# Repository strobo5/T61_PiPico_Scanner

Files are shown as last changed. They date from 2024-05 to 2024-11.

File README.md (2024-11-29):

Keyboard scanner for a Thinkpad T61 keyboard, using the original connector,
salvaged from a retired T61, and a Raspberry Pi Pico H. Components on the BOM:

* 1x Molex 54363-0489 (WM6787CT-ND on Digikey)
* 1x Raspberry Pi Pico (with or without headers)
* 1x capacitor SMD 0603 2.2 uF
* 1x capacitor SMD 0603 100 nF
* 1x p-MOSFET TSM2305CX or similar (optional, for external 5V, e.g. a battery)
* 2x n-MOSFET 2N7002 or similar
* 4x resistor SMD 0603 10 kOhm
* 1x resistor SMD 0603 22 kOhm

Based on work by thedalles77 (schematics) and WarhawkCZ (QMK variant). HDR also
had the same idea of having the keyboard connector and the MCU module on
opposite sides to save space.
- https://github.com/thedalles77/USB_Laptop_Keyboard_Controller/tree/master/Example_Keyboards/Lenovo_ThinkPad_T61/Teensy%20LC
- https://forum.thinkpads.com/viewtopic.php?t=134293
- https://github.com/HDR/USB_Laptop_Keyboard_Controller

Thanks @tpcware for the KiCad symbol, footprint and 3D model for the Raspberry
Pi Pico. I butchered the footprint to get a THT-only variant.
https://github.com/ncarandini/KiCad-RP-Pico

Good advice came from thedalles77 on instructables to lay out the connections
on a piece of paper before assigning the nets in the schematic editor.
https://www.instructables.com/How-to-Make-a-USB-Laptop-Keyboard-Controller/

When using a Pico W it might be possible to extend this with Bluetooth, hence
the solder pads for wires to an external battery charger + 5V converter. This
might not work too well though; the keyboard's bottom is a metal shield that
probably kills the wireless transmission when the Pico W is right underneath.

Ordered on JLCPCB. The via size (0.5 mm hole, 1.1 mm overall diameter) is small
enough and does not cost extra.

The 0.5 mm drills and vias could be done by hand (with wire soldered through
the hole) if making the PCB at home.

## Third-party components

The following components in this repository are not my work:

Symbols:

* AA01B-S040VA1 - probably by Jiri Panacek (WarhawkCZ)
* Molex_54363-0489:543630489 - Copyright held by EMA Design Automation, ® Inc., all rights reserved

Footprints:

* T61_Kb_Scanner:RPi_Pico_H - adapted from the one by @tpcware
* T61_Kb_Scanner:AA01B-S040VA1 - unknown
* T61_Kb_Scanner:WM6787CT-ND - unknown
* Molex_54363-0489:CON_543630489 - Copyright held by EMA Design Automation, ® Inc., all rights reserved

## License

Copyright 2023-2024 Michael Büchler
SPDX-License-Identifier: Apache-2.0 WITH SHL-2.1

The schematics and PCB design in this repository shall use the Solderpad Hardware License v 2.1 (the “License”); you may not use this file except in compliance with the License, or, at your option, the Apache License version 2.0. You may obtain a copy of the License at

https://solderpad.org/licenses/SHL-2.1/

Unless required by applicable law or agreed to in writing, any work distributed under the License is distributed on an “AS IS” BASIS, WITHOUT WARRANTIES OR CONDITIONS OF ANY KIND, either express or implied. See the License for the specific language governing permissions and limitations under the License.

## Images

The keyboard case in the picture is this one:
https://www.printables.com/model/877321-thinkpad-t61-keyboard-base

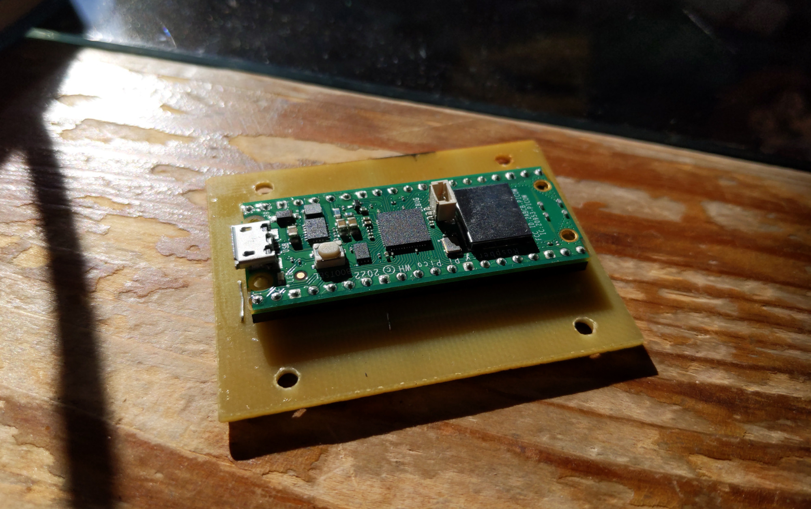
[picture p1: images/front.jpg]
PCB top

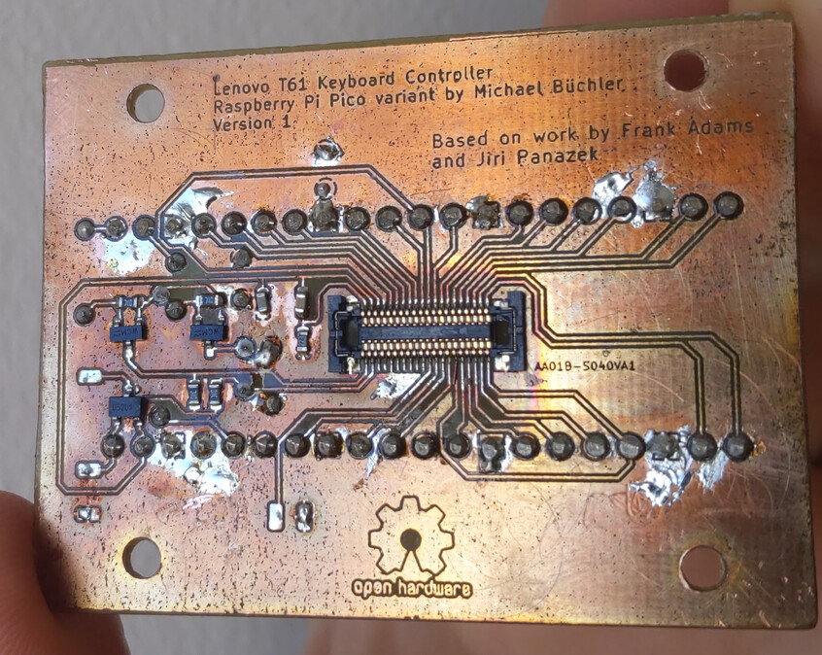
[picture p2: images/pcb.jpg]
PCB bottom

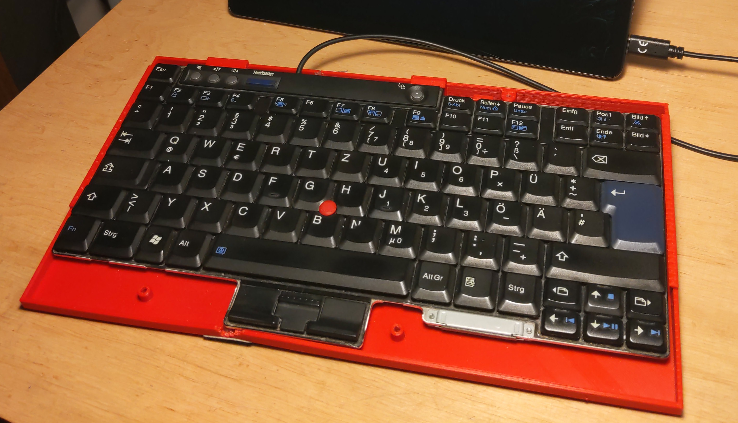
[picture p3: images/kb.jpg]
Assembled keyboard


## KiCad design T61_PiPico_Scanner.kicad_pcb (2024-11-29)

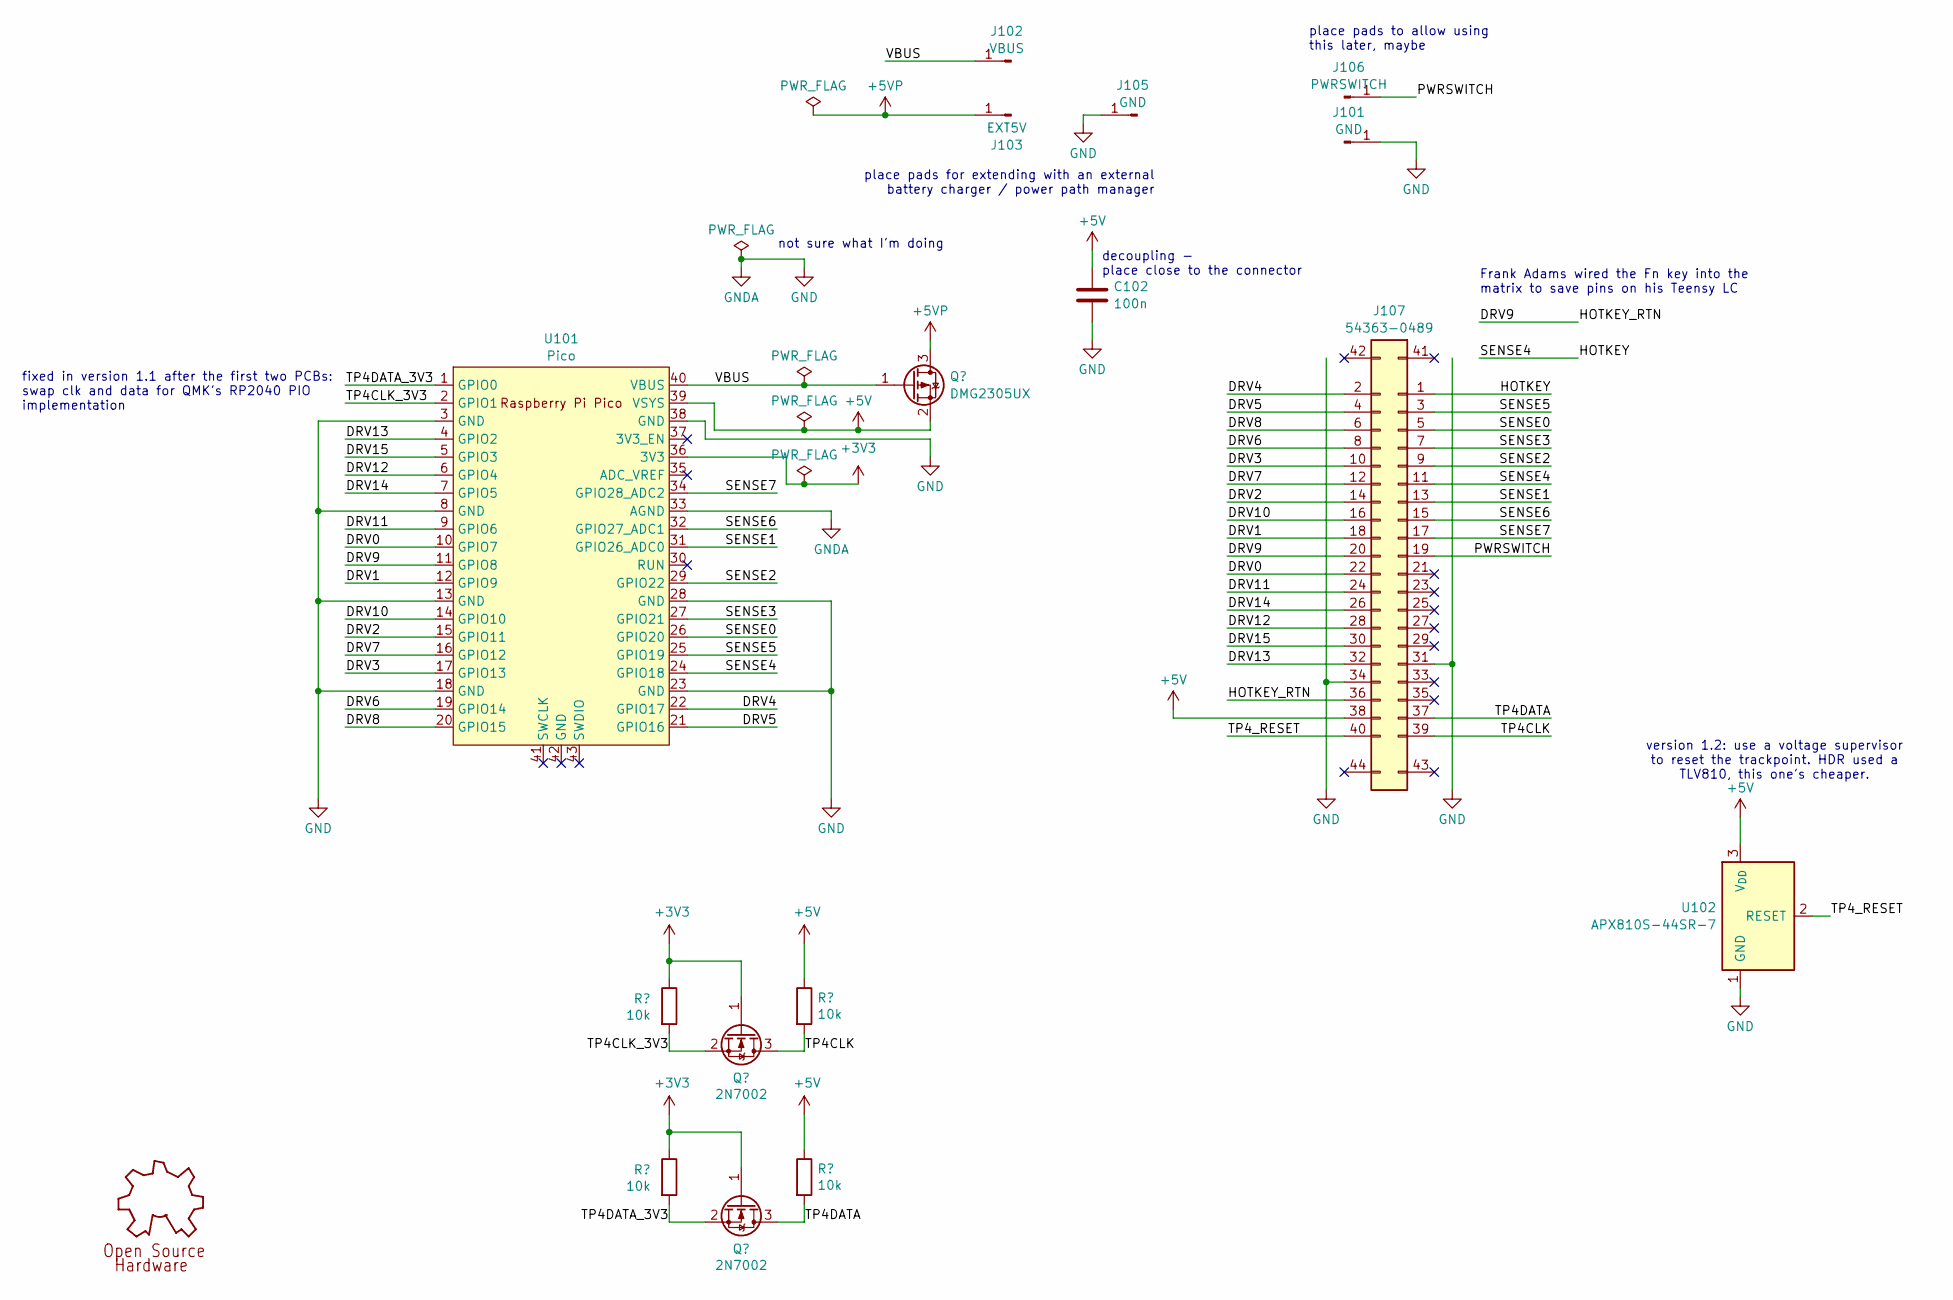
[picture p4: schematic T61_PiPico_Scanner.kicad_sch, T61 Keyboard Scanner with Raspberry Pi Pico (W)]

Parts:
C102: 100n; C_0603_1608Metric
GOLD_ORB_SM101: OSHWLOGOLOGO5MM; OSHW-Logo_5.7x6mm_Copper
J101, J105: GND; SolderWirePad_1x01_SMD_1x2mm
J102: VBUS; SolderWirePad_1x01_SMD_1x2mm
J103: EXT5V; SolderWirePad_1x01_SMD_1x2mm
J106: PWRSWITCH; SolderWirePad_1x01_SMD_1x2mm
J107: 54363-0489; CON_543630489_var
Q101, Q102: 2N7002; SOT-23
Q103: DMG2305UX; SOT-23
R104, R105, R106, R107: 10k; R_0603_1608Metric
U101: Pico; RPi_Pico_SMD_TH
U102: APX810S-44SR-7; SOT-23

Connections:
+3V3: Q101.1 (G), Q102.1 (G), R104.1, R105.1, U101.36 (3V3)
+5V: C102.1, J107.38, Q103.2 (S), R106.1, R107.1, U101.39 (VSYS), U102.3 (V_{DD})
+5VP: J103.1, Q103.3 (D)
/DRV0: J107.22, U101.10 (GPIO7)
/DRV1: J107.18, U101.12 (GPIO9)
/DRV2: J107.14, U101.15 (GPIO11)
/DRV3: J107.10, U101.17 (GPIO13)
/DRV4: J107.2, U101.22 (GPIO17)
/DRV5: J107.4, U101.21 (GPIO16)
/DRV6: J107.8, U101.19 (GPIO14)
/DRV7: J107.12, U101.16 (GPIO12)
/DRV8: J107.6, U101.20 (GPIO15)
/DRV9: J107.20, J107.36, U101.11 (GPIO8)
/DRV10: J107.16, U101.14 (GPIO10)
/DRV11: J107.24, U101.9 (GPIO6)
/DRV12: J107.28, U101.6 (GPIO4)
/DRV13: J107.32, U101.4 (GPIO2)
/DRV14: J107.26, U101.7 (GPIO5)
/DRV15: J107.30, U101.5 (GPIO3)
/HOTKEY: J107.1, J107.11, U101.24 (GPIO18)
/PWRSWITCH: J106.1, J107.19
/SENSE0: J107.5, U101.26 (GPIO20)
/SENSE1: J107.13, U101.31 (GPIO26_ADC0)
/SENSE2: J107.9, U101.29 (GPIO22)
/SENSE3: J107.7, U101.27 (GPIO21)
/SENSE5: J107.3, U101.25 (GPIO19)
/SENSE6: J107.15, U101.32 (GPIO27_ADC1)
/SENSE7: J107.17, U101.34 (GPIO28_ADC2)
/TP4CLK: J107.39, Q101.3 (D), R106.2
/TP4CLK_3V3: Q101.2 (S), R104.2, U101.2 (GPIO1)
/TP4DATA: J107.37, Q102.3 (D), R107.2
/TP4DATA_3V3: Q102.2 (S), R105.2, U101.1 (GPIO0)
/TP4_RESET: J107.40, U102.2 (RESET)
/VBUS: J102.1, Q103.1 (G), U101.40 (VBUS)
GND: C102.2, J101.1, J105.1, J107.31, J107.34, U101.3 (GND), U101.8 (GND), U101.13 (GND), U101.18 (GND), U101.23 (GND), U101.28 (GND), U101.33 (AGND), U101.38 (GND), U102.1 (GND)

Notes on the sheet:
decoupling - place close to the connector
place pads to allow using this later, maybe
fixed in version 1.1 after the first two PCBs: swap clk and data for QMK's RP2040 PIO implementation
place pads for extending with an external battery charger / power path manager
Frank Adams wired the Fn key into the matrix to save pins on his Teensy LC
version 1.2: use a voltage supervisor to reset the trackpoint. HDR used a TLV810, this one's cheaper.
not sure what I'm doing

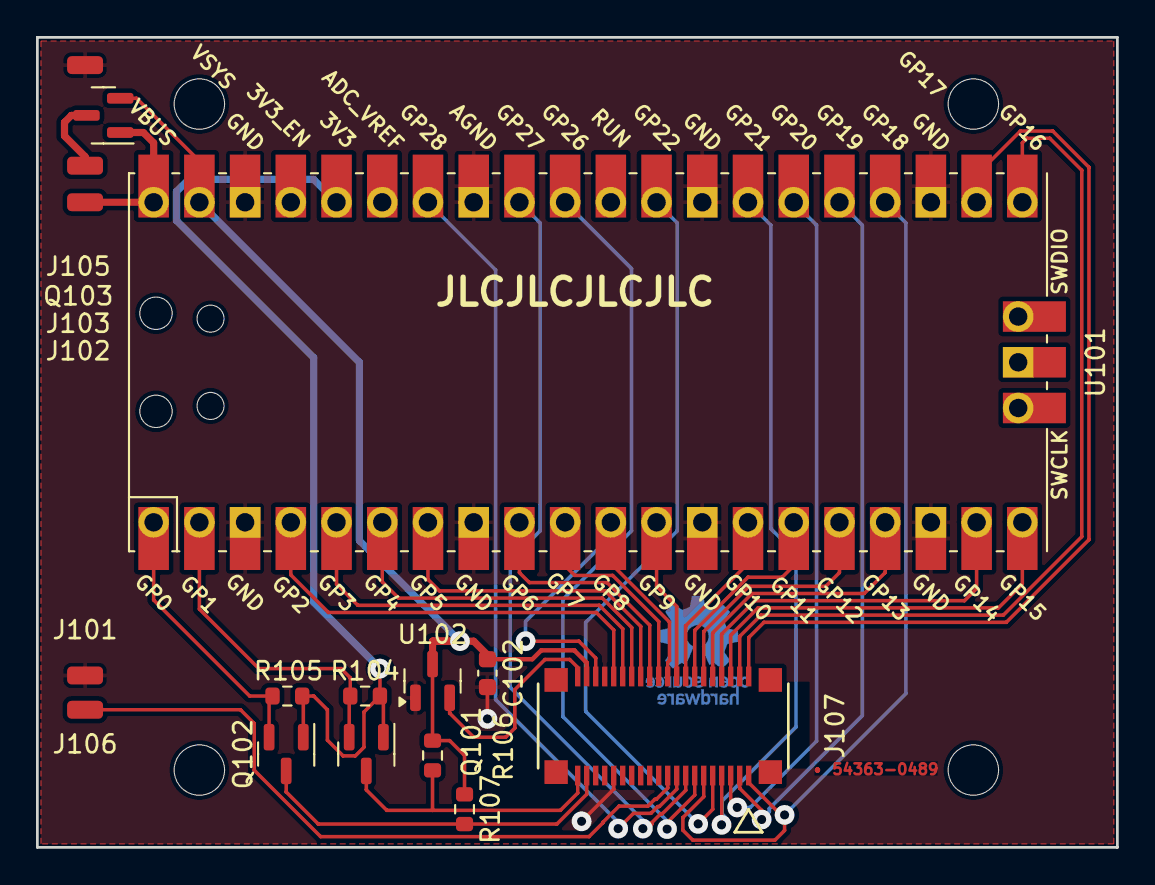
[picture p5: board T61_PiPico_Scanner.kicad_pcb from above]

Board: 2 copper layers, 60.0 x 45.0 mm, 21 parts (1 on the bottom side), 35 nets.

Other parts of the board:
@HOLE0, @HOLE1, @HOLE2, @HOLE3: (no value)

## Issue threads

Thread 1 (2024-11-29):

Does the pointing stick work properly?

bommbo, 2024-11-29:
Bro, Does the pointing stick work properly?

strobo5, 2024-11-29:
Yeah, I use it every day and I love it. Just sometimes (every few weeks or twice a day) it stops working and I have to plug the cable in and out. Not often enough to bother me.

This is with the first version. In the second version (tagged 2.0; the one that until now I had failed to `git push` properly) has a reset IC for the Trackpoint, which might help.

As of now the only user of version 2 is my colleague and his X220 keyboard. Here the trackpoint doesn't work properly; it might need its own 3.3V via pin 35 of the connector. Also the Fn key is broken.

bommbo, 2024-11-29:
Amazing!!!

gitaen, 2025-03-04:
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

Regarding the Fn key not working on the X220 keyboard it is probably due to this same issue https://github.com/thedalles77/USB_Laptop_Keyboard_Controller/issues/22#issue-2895649409.

HOTKEY_RTN is located on pin 34 on the T420/X220 keyboard.

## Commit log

2024-05-12 rev 1.1: swap PS/2 clk and data for QMK's RP2040 PIO implementation
    The only two boards with the wrong order were fixed manually.
    [T61_PiPico_Scanner.kicad_pcb, T61_PiPico_Scanner.kicad_sch]
2024-05-12 Add images and link to the case 3D file
2024-08-23 Update files to KiCad 8.0
    [T61_PiPico_Scanner.kicad_pcb, T61_PiPico_Scanner.kicad_sch]
2024-08-24 Re-write project-local symbols and footprints
2024-08-25 Add Molex 0543630489 connector
    Downloaded from UltraLibrarian through the Molex product page. See
    copyright information in the README.
2024-08-25 version 1.2: reset IC; Molex 54363-0489
    [T61_PiPico_Scanner.kicad_pcb, T61_PiPico_Scanner.kicad_sch]
2024-11-29 version 2.0: use SMT version of Pi Pico
    Now use two layers to allow keyboard connector and Pi Pico to both be on
    the top side.
    Mechanically incompatible (connector position / mounting holes) but
    electrically identical to version 1, i.e. the (QMK) firmware can stay
    the same.
    [T61_PiPico_Scanner.kicad_pcb, T61_PiPico_Scanner.kicad_sch]

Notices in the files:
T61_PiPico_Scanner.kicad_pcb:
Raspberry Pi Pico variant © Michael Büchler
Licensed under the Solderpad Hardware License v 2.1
